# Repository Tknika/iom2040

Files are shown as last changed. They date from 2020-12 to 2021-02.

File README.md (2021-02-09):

# IoM2040

## Introduction

**IoM2040** (hardware for [IoMBian OS](https://github.com/Tknika/iombian) ) is a Raspberry Pi 4 based gateway hardware for industrial teaching area. 

It has been developed mainly for teachers (educational environments), in order to facilitate the implementation of IoM (Internet of Machines) and IIoT (Industrial Internet of Things) systems in embedded devices.
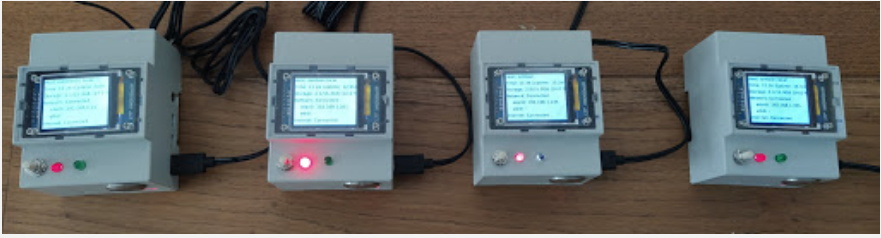
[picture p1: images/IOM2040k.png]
IOM2040

The initial configuration have a push button to wake or sleep down the hardware in a secure way and red LED to monitor the hardware running [iom shutdown controller](https://github.com/Tknika/iom2040-shutdown-controller).

 It also have a switch and a green LED for a plug an teach practicing with Node Red.  
 
It has been entirely build to be working as a one with [IoMBian OS ](https://github.com/Tknika/iombian) firmware.

## List of elements
|Elements| Quantity | Link | 
|---|---|---|
| Raspberry Pi 4 Kit| 1 | |
| 1.7'' LCD Screen| 1 |[1,77 LCD - Amazon](https://www.amazon.es/AZDelivery-Pantalla-Pulgadas-p%C3%ADxeles-Display/dp/B07TJGF8HS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)|
| DIN enclosure| 1 |[DIN enclosure - Amazon](https://www.amazon.es/GeeekPi-Caja-para-Raspberry-riel/dp/B083B93PPM)|
| Push button| 1 |[Button RS Online](https://es.rs-online.com/web/p/botones-pulsadores/0320988/)|
| Switch| 1 |[Switch RS Online](https://es.rs-online.com/web/p/botones-pulsadores/1115778/)|
| 5mm LED| 2 ||
| 68 Ω resistor| 2 ||
| Female-Female headers| 17 ||

> **Warning**: Try to buy locally ```nearest store```.

## Scheme
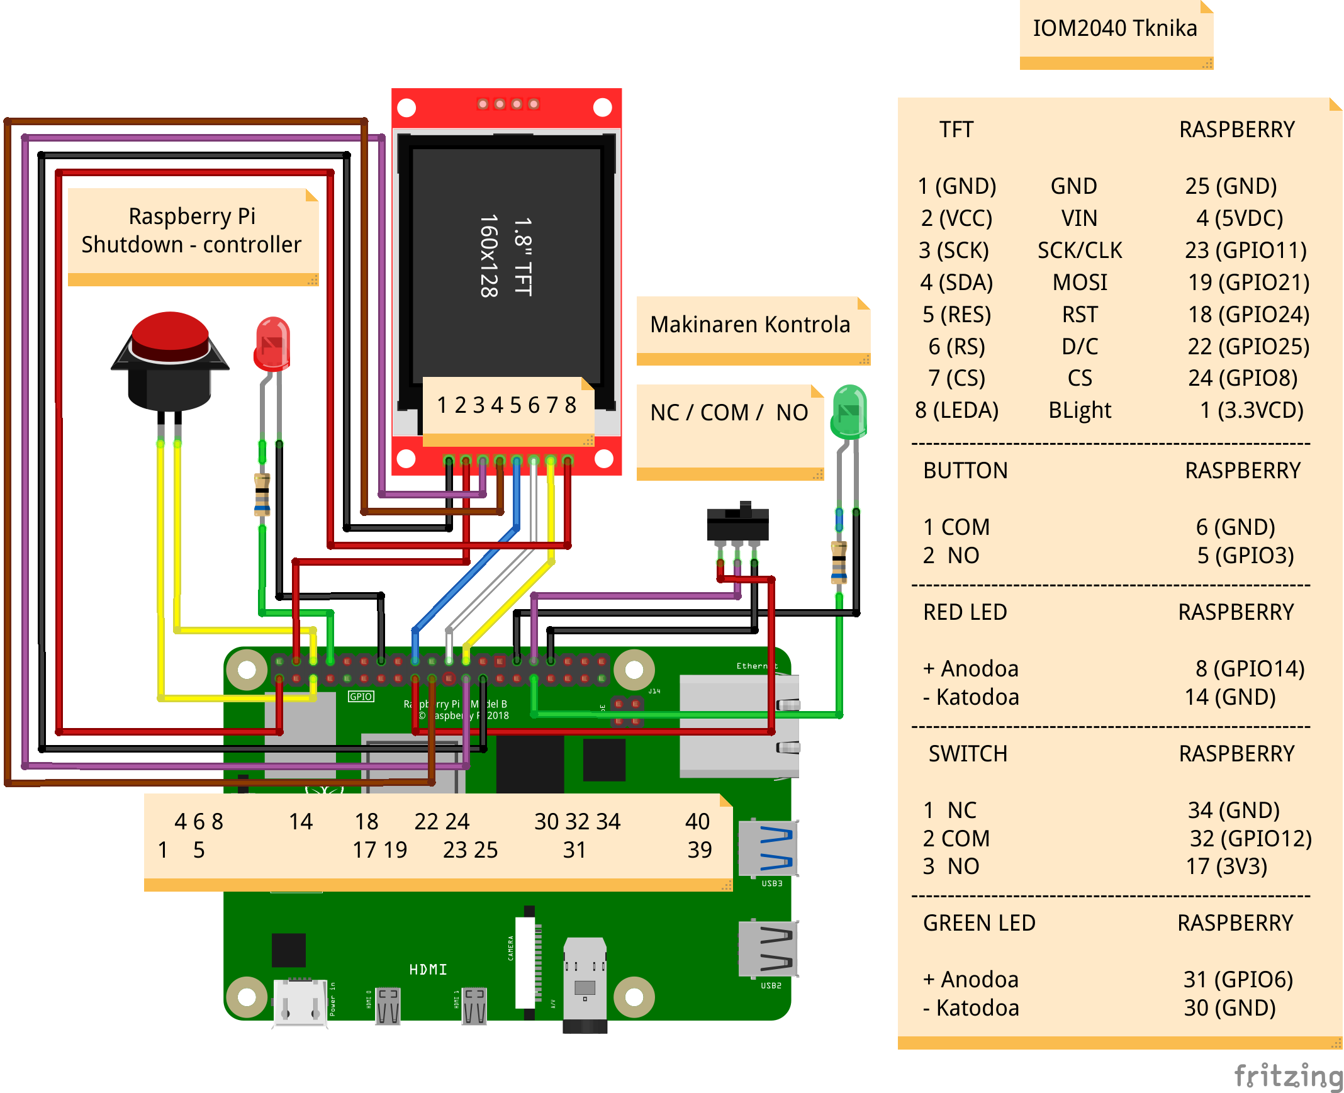
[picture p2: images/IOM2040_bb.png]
Scheme


  - (For a more detailed raspberry pi 4 pinout, please refer to the following [link](https://www.raspberrypi.org/documentation/usage/gpio/))

## Making progress

Firstly we recommend to make the 3D DIN case holes and place the elements on then. 

	 - LED 		hole 		Ø5mm
	 - Button 	hole 		Ø6mm
	 - Switch 	hole 		Ø19mm
	 - LCD		holes		Ø2mm

These are the measurements for the 3D enclosure holes:

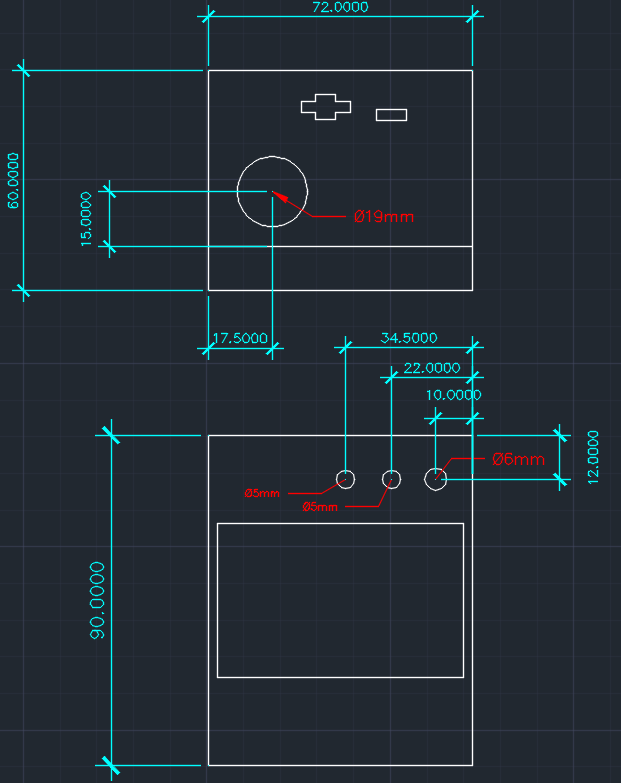
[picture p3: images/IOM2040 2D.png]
3D enclosure


And these the measurements of the screen location, although we recommend to glue the LCD to the screen, make the Ø2 holes and release and fix it with bolts afterwards.

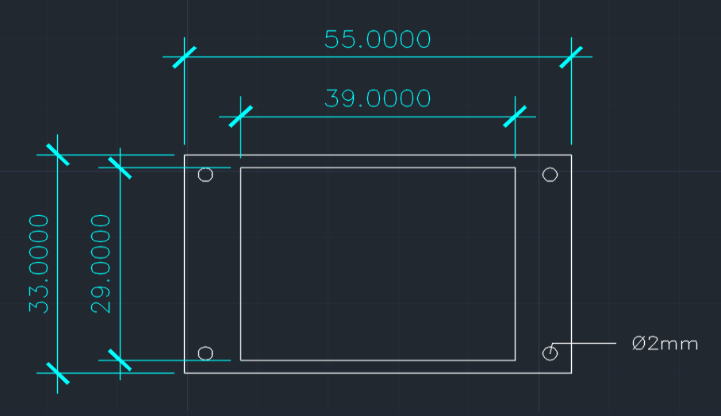
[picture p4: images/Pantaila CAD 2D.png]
LCD

## Soldering

Prepare the elements with a female header in every pin on them. It requires a bit of soldering.

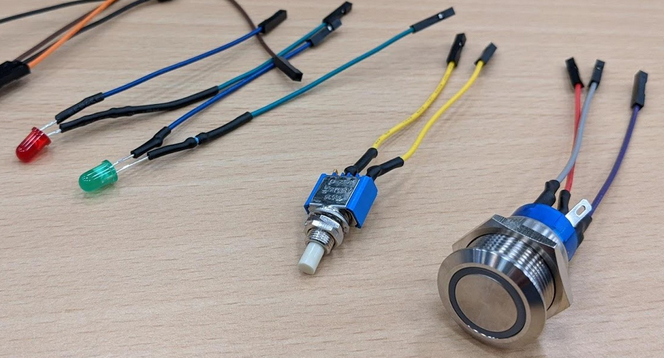
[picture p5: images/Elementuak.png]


## Mounting

 - Place all the components in their pins following the related scheme above.
 - Close the enclosure.
 - Burn the latest [IoMBian OS ](https://github.com/Tknika/iombian)  software on the SD.
 - Find the gateway using the [IoMBian discover tool](https://github.com/Tknika/iombian-discover).
 - Enjoy!

## Authors

(c) 2020 [Tknika](https://tknika.eus/) ([Aitor Iturrioz](https://github.com/bodiroga) ,  [Aitor Azpiroz](https://github.com/axpirina))

Licensed under the Apache License, Version 2.0 (the "License");
you may not use this file except in compliance with the License.
You may obtain a copy of the License at

    http://www.apache.org/licenses/LICENSE-2.0

Unless required by applicable law or agreed to in writing, software
distributed under the License is distributed on an "AS IS" BASIS,
WITHOUT WARRANTIES OR CONDITIONS OF ANY KIND, either express or implied.
See the License for the specific language governing permissions and
limitations under the License.

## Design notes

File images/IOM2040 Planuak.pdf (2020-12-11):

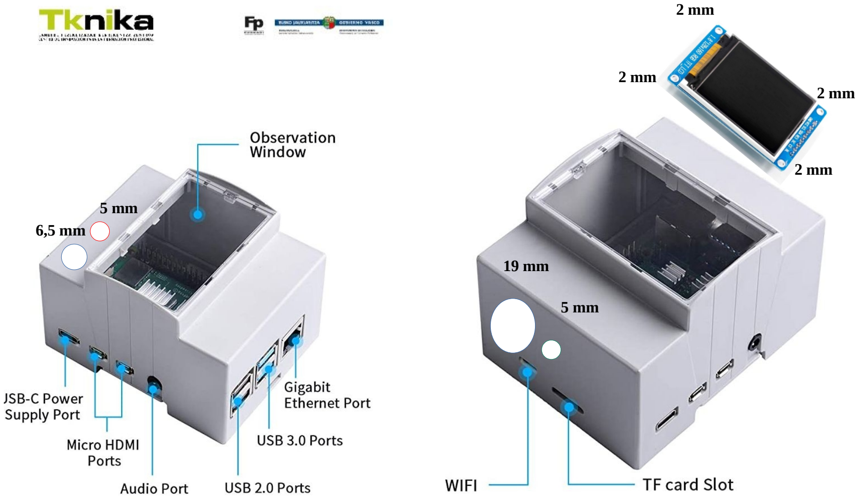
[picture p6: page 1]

### 5 mm

### 5 mm

### 19 mm

6,5 mm

### 2 mm

### 2 mm

### 2 mm

### 2 mm

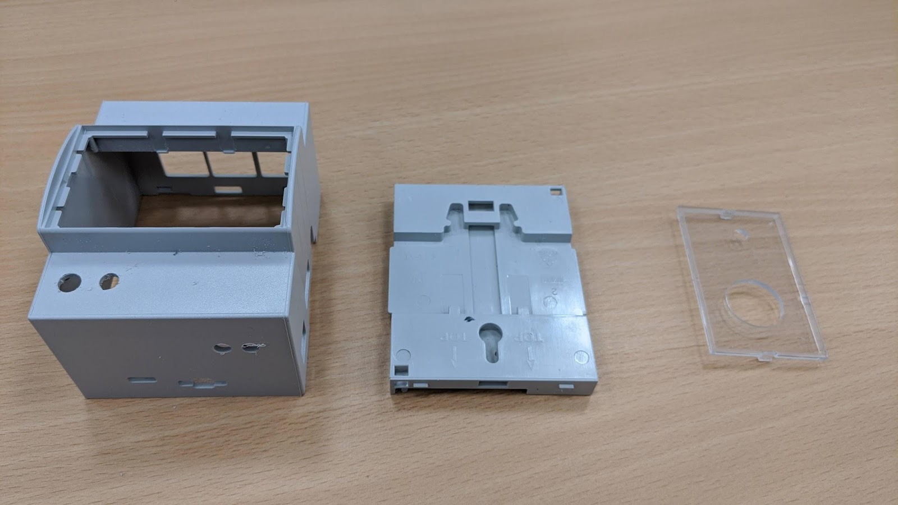
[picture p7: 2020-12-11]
images/3D enclosure.jpg

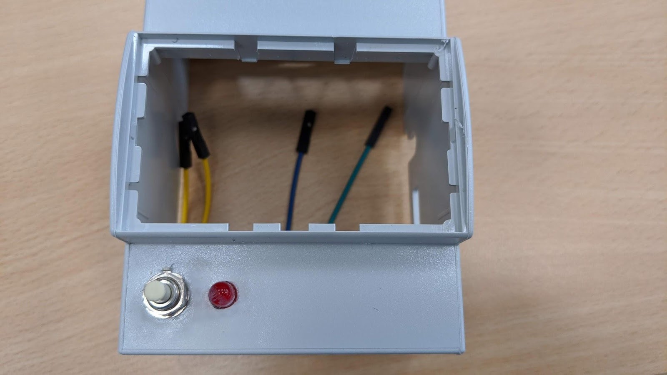
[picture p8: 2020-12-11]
images/Working.jpg

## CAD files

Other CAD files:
drawings/Zuloak 2D .dwg
drawings/IOM2040 2D.dwg
